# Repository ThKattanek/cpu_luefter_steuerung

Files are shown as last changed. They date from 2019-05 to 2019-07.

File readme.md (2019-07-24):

# CPU-Lüfter Steuerung
Steuerung eines CPU Lüfters per Attiny24a und Anzeige auf 7-Segmentanzeige. Bedienung per Taster.

### [Latest version here](https://github.com/ThKattanek/cpu_luefter_steuerung/releases/latest)

## Bilder
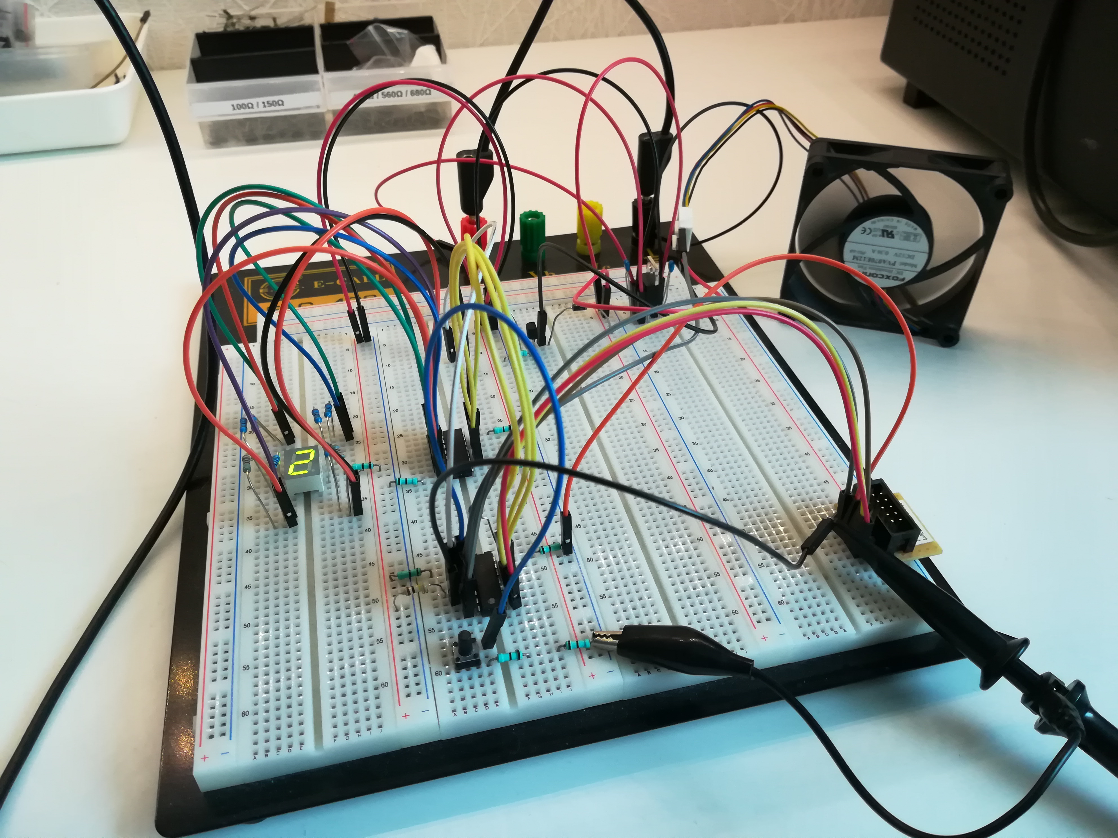
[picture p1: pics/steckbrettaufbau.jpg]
Aufbau

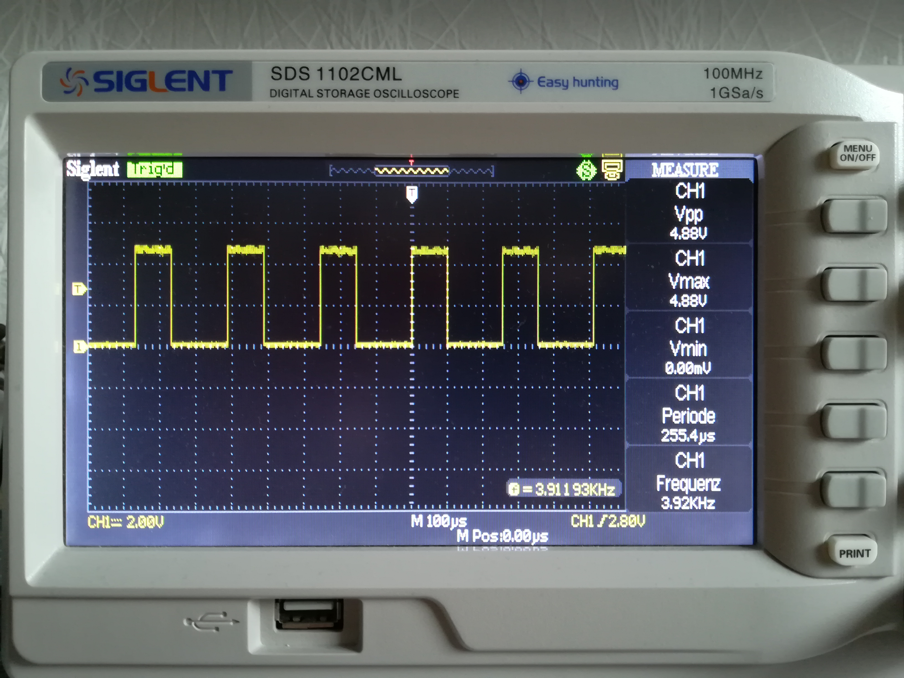
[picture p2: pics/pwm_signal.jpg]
PWM Signal

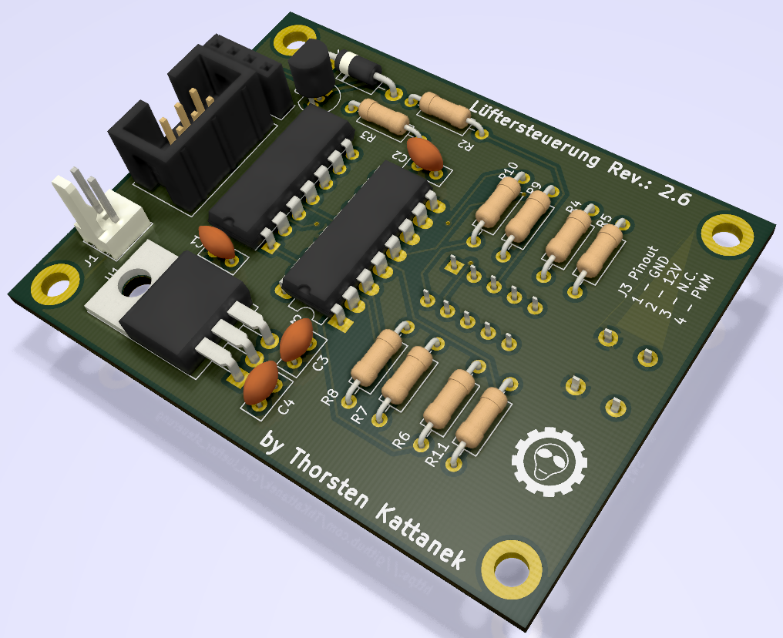
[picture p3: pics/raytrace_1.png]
PCB1

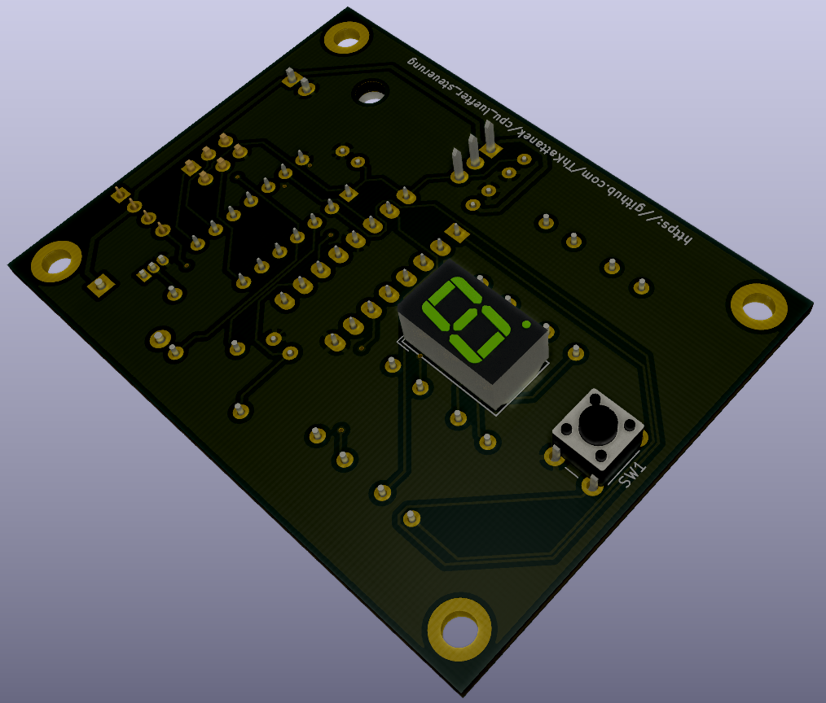
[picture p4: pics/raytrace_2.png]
PCB2


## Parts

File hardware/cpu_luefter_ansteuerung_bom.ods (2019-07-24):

Reference | Value | Footprint
C1 | 100n | Capacitor_THT:C_Disc_D5.0mm_W2.5mm_P2.50mm
C2 | 100n | Capacitor_THT:C_Disc_D5.0mm_W2.5mm_P2.50mm
C3 | 0,33u | Capacitor_THT:C_Disc_D5.0mm_W2.5mm_P2.50mm
C4 | 0,1u | Capacitor_THT:C_Disc_D5.0mm_W2.5mm_P2.50mm
D1 | 1N4001 | Diode_THT:D_DO-41_SOD81_P10.16mm_Horizontal
J1 | Power 12V DC | Connector_Molex:Molex_KK-254_AE-6410-02A_1x02_P2.54mm_Vertical
J2 | ISP | Connector_IDC:IDC-Header_2x03_P2.54mm_Vertical
J3 | CPU Lüfter | Connector_PinSocket_2.54mm:PinSocket_1x04_P2.54mm_Vertical
Q1 | BC337 | Package_TO_SOT_THT:TO-92_Inline
R10 | 560 | Resistor_THT:R_Axial_DIN0207_L6.3mm_D2.5mm_P10.16mm_Horizontal
R11 | 560 | Resistor_THT:R_Axial_DIN0207_L6.3mm_D2.5mm_P10.16mm_Horizontal
R2 | 10k | Resistor_THT:R_Axial_DIN0207_L6.3mm_D2.5mm_P10.16mm_Horizontal
R3 | 220 | Resistor_THT:R_Axial_DIN0207_L6.3mm_D2.5mm_P10.16mm_Horizontal
R4 | 560 | Resistor_THT:R_Axial_DIN0207_L6.3mm_D2.5mm_P10.16mm_Horizontal
R5 | 560 | Resistor_THT:R_Axial_DIN0207_L6.3mm_D2.5mm_P10.16mm_Horizontal
R6 | 560 | Resistor_THT:R_Axial_DIN0207_L6.3mm_D2.5mm_P10.16mm_Horizontal
R7 | 560 | Resistor_THT:R_Axial_DIN0207_L6.3mm_D2.5mm_P10.16mm_Horizontal
R8 | 560 | Resistor_THT:R_Axial_DIN0207_L6.3mm_D2.5mm_P10.16mm_Horizontal
R9 | 560 | Resistor_THT:R_Axial_DIN0207_L6.3mm_D2.5mm_P10.16mm_Horizontal
SW1 | SW_Push | Button_Switch_THT:SW_PUSH_6mm_H5mm
U1 | L7805 | Package_TO_SOT_THT:TO-220-3_Horizontal_TabDown
U2 | ATtiny24A-PU | Package_DIP:DIP-14_W7.62mm
U3 | 74HC595 | Package_DIP:DIP-16_W7.62mm_LongPads
U4 | KCSA02-123 | Display_7Segment:HDSP-7801

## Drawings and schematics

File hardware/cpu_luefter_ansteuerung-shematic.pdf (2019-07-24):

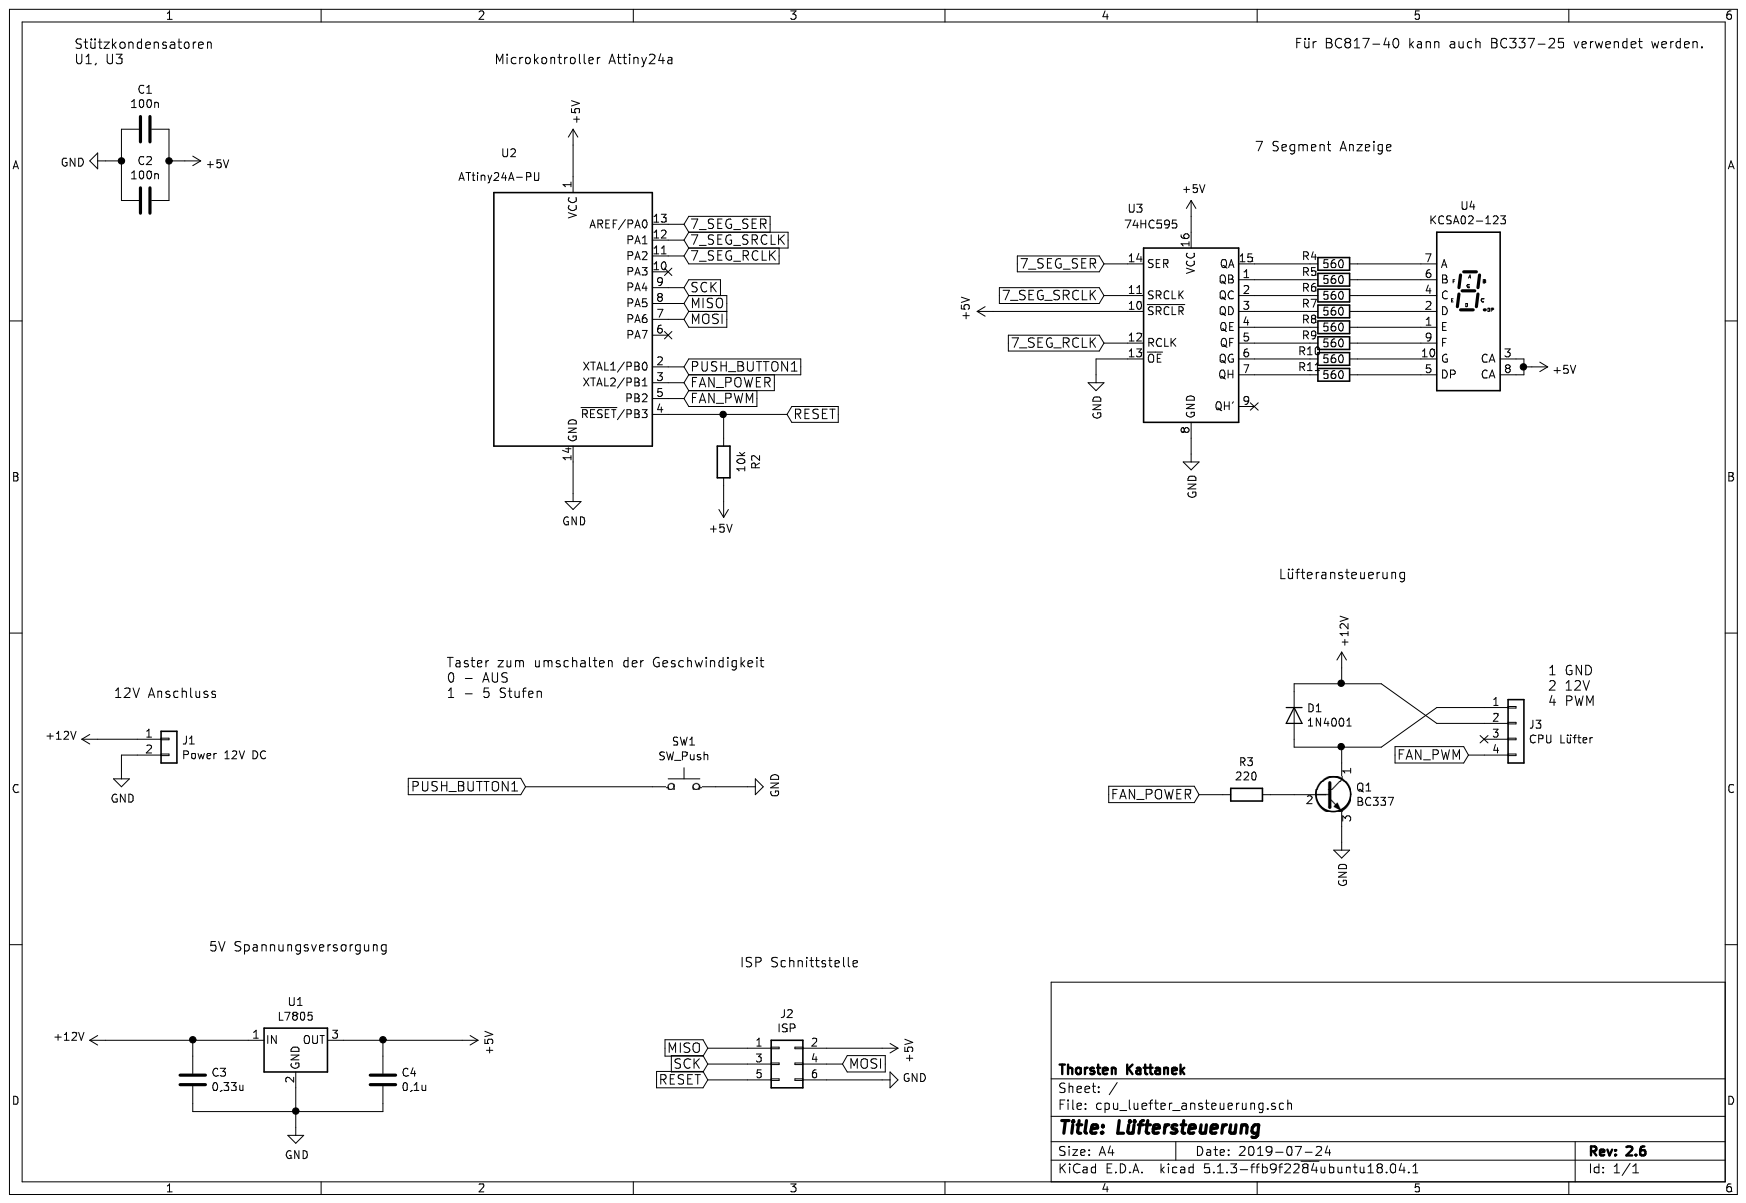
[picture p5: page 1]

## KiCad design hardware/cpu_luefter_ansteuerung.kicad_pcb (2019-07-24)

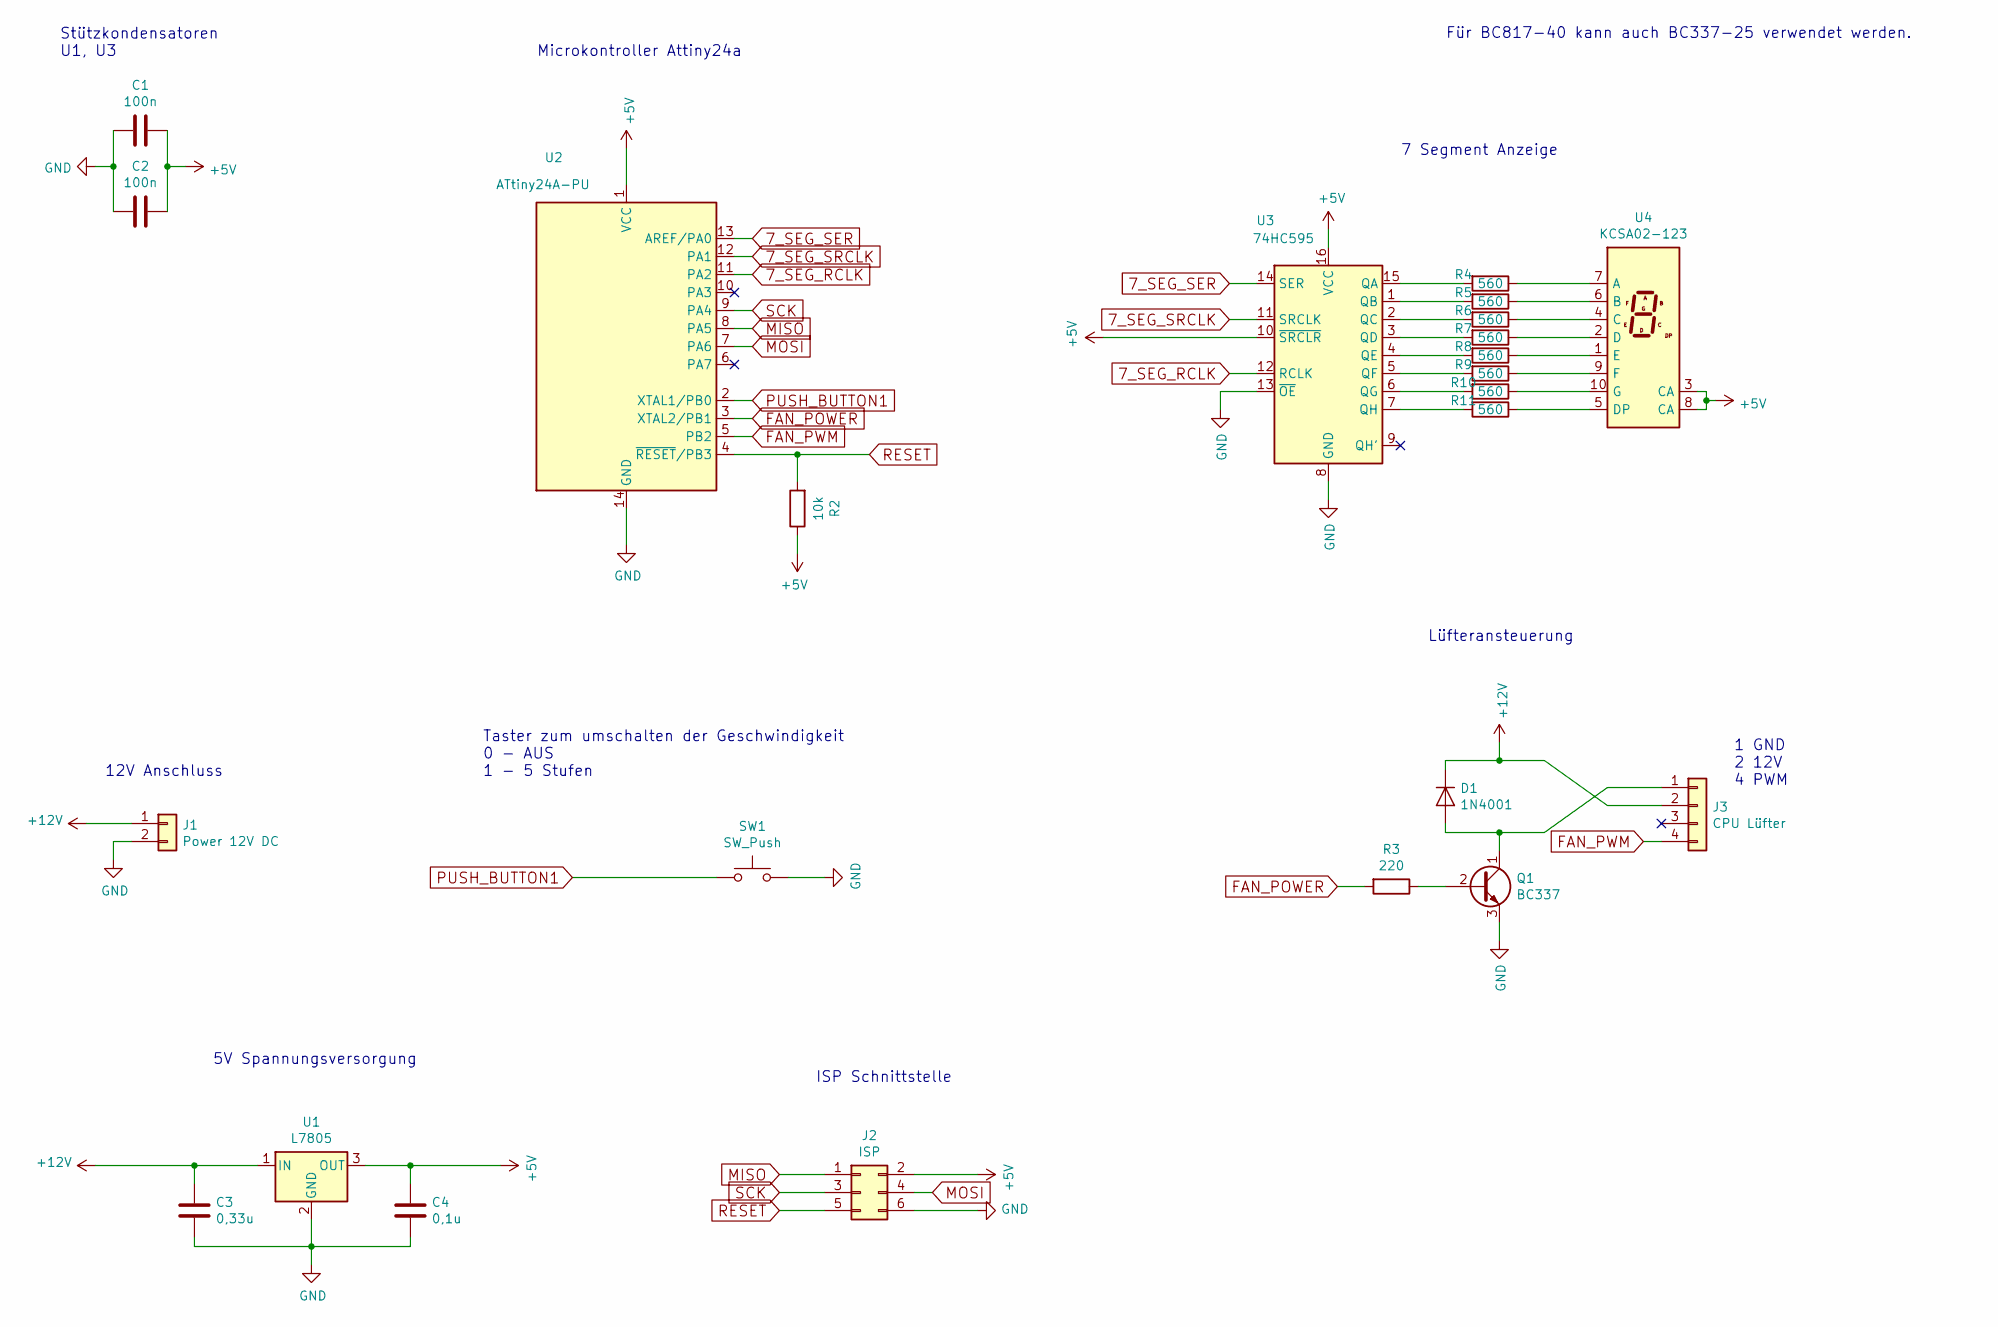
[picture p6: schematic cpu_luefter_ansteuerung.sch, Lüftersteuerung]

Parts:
C1, C2: 100n; C_Disc_D5.0mm_W2.5mm_P2.50mm
C3: 0,33u; C_Disc_D5.0mm_W2.5mm_P2.50mm
C4: 0,1u; C_Disc_D5.0mm_W2.5mm_P2.50mm
D1: 1N4001; D_DO-41_SOD81_P10.16mm_Horizontal
J1: Power 12V DC; Molex_KK-254_AE-6410-02A_1x02_P2.54mm_Vertical
J2: ISP; IDC-Header_2x03_P2.54mm_Vertical
J3: CPU Lüfter; PinSocket_1x04_P2.54mm_Vertical
Q1: BC337; TO-92_Inline
R2: 10k; R_Axial_DIN0207_L6.3mm_D2.5mm_P10.16mm_Horizontal
R3: 220; R_Axial_DIN0207_L6.3mm_D2.5mm_P10.16mm_Horizontal
R4, R5, R6, R7, R8, R9, R10, R11: 560; R_Axial_DIN0207_L6.3mm_D2.5mm_P10.16mm_Horizontal
SW1: SW_Push; SW_PUSH_6mm_H5mm
U1: L7805; TO-220-3_Horizontal_TabDown
U2: ATtiny24A-PU; DIP-14_W7.62mm
U3: 74HC595; DIP-16_W7.62mm_LongPads
U4: KCSA02-123; HDSP-7801

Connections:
7_SEG_RCLK: U2.11 (PA2), U3.12 (RCLK)
7_SEG_SER: U2.13 (AREF/PA0), U3.14 (SER)
7_SEG_SRCLK: U2.12 (PA1), U3.11 (SRCLK)
+5V: C1.1, C2.1, C4.1, J2.2, R2.1, U1.3 (OUT), U2.1 (VCC), U3.10 (~SRCLR), U3.16 (VCC), U4.3 (CA), U4.8 (CA)
+12V: C3.1, D1.1 (K), J1.1, J3.2, U1.1 (IN)
FAN_POWER: R3.2, U2.3 (XTAL2/PB1)
FAN_PWM: J3.4, U2.5 (PB2)
GND: C1.2, C2.2, C3.2, C4.2, J1.2, J2.6, Q1.3 (E), SW1.2, U1.2 (GND), U2.14 (GND), U3.8 (GND), U3.13 (~OE)
MISO: J2.1, U2.8 (PA5)
MOSI: J2.4, U2.7 (PA6)
unnamed: D1.2 (A), J3.1, Q1.1 (C)
unnamed: Q1.2 (B), R3.1
unnamed: R4.1, U4.7 (A)
unnamed: R4.2, U3.15 (QA)
unnamed: R5.1, U4.6 (B)
unnamed: R5.2, U3.1 (QB)
unnamed: R6.1, U4.4 (C)
unnamed: R6.2, U3.2 (QC)
unnamed: R7.1, U4.2 (D)
unnamed: R7.2, U3.3 (QD)
unnamed: R8.1, U4.1 (E)
unnamed: R8.2, U3.4 (QE)
unnamed: R9.1, U4.9 (F)
unnamed: R9.2, U3.5 (QF)
unnamed: R10.1, U4.10 (G)
unnamed: R10.2, U3.6 (QG)
unnamed: R11.1, U4.5 (DP)
unnamed: R11.2, U3.7 (QH)
PUSH_BUTTON1: SW1.1, U2.2 (XTAL1/PB0)
RESET: J2.5, R2.2, U2.4 (~RESET~/PB3)
SCK: J2.3, U2.9 (PA4)

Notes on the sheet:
Für BC817-40 kann auch BC337-25 verwendet werden.
5V Spannungsversorgung
12V Anschluss
Taster zum umschalten der Geschwindigkeit 0 - AUS 1 - 5 Stufen
1 GND 2 12V 4 PWM
Stützkondensatoren U1, U3
ISP Schnittstelle
Microkontroller Attiny24a
7 Segment Anzeige
Lüfteransteuerung

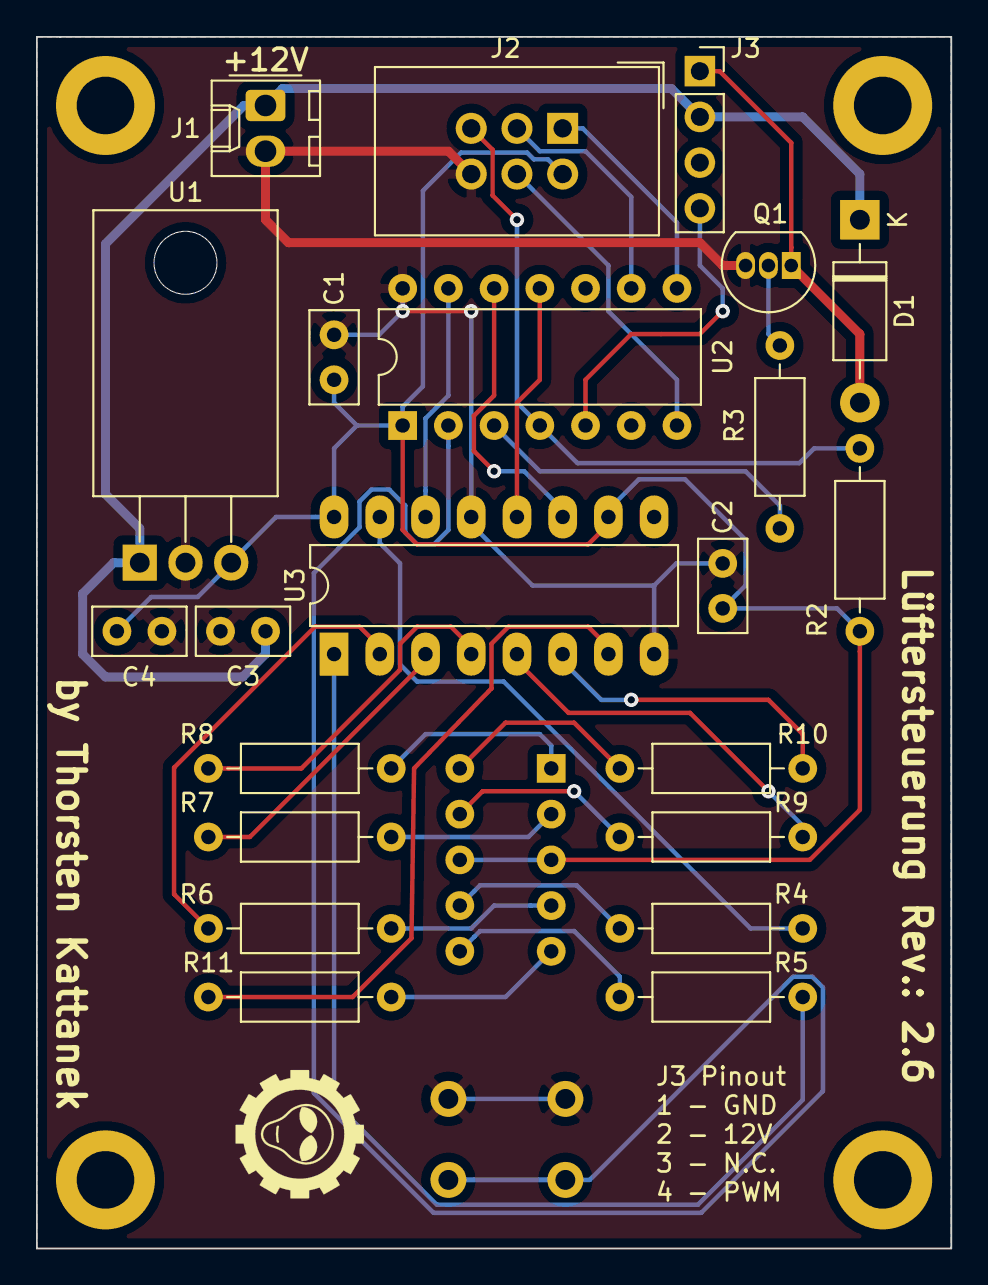
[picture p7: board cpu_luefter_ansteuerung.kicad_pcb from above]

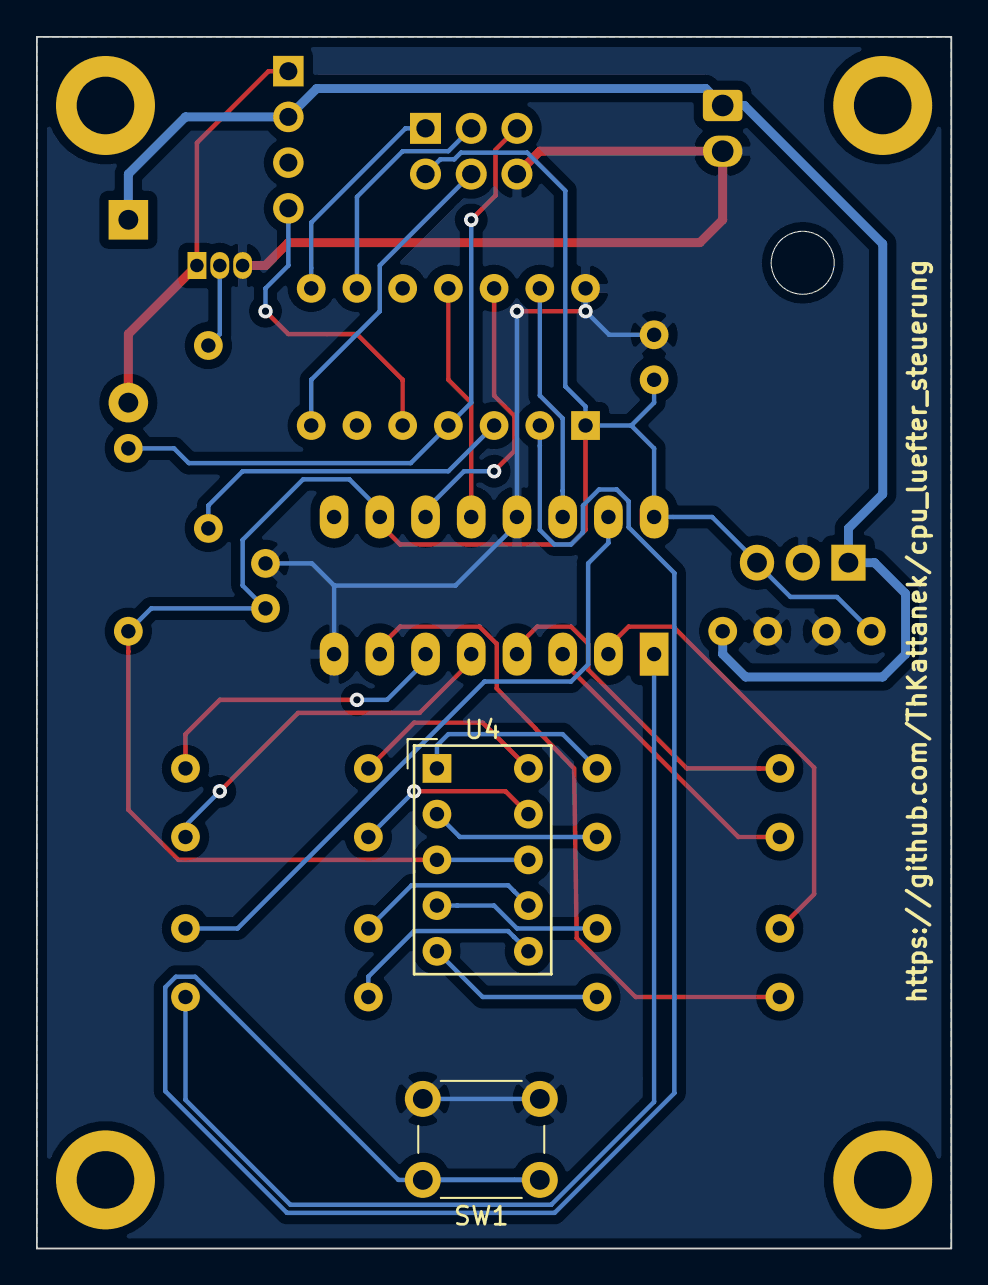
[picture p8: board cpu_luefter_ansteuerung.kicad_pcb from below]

Board: 2 copper layers, 50.8 x 67.3 mm, 24 parts (2 on the bottom side), 31 nets.

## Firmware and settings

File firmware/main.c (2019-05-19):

/* Name: main.c
 * Projekt: cpu_lueftersteuerung
 * Author: Thorsten Kattanek
 * Geändert am: 19.05.2019
 * Copyright: Thorsten Kattanek
 * License: GNU GPL v2 (see License.txt), GNU GPL v3 or proprietary (CommercialLicense.txt)
 *
 */

#define F_CPU   8000000UL
    
#include <avr/io.h>
#include <avr/wdt.h>
#include <avr/interrupt.h>
#include <util/delay.h>
#include <avr/pgmspace.h>   /* benötigt von usbdrv.h */

// PinOut
// PB1 - FAN_POWER
// PB2 - FAN_PWM

// PA0 - 7_SEG_SER
// PA1 - 7_SEG_SRCLK
// PA2 - 7_SEG_RCLK

// PB0 - PUSH_BUTTON1

void InitMotor(void);
void InitPWMChannel(void);
void Init7Segment(void);
void InitInputs(void);

void MotorOn(void);
void MotorOff(void);
void SetMotorSpeed(unsigned char speed);

void Set7Segment(uint8_t value);
void Set7SegmentNumber(uint8_t num);

int main(void)
{
    InitMotor();
    InitPWMChannel();
    Init7Segment();
    InitInputs();

    Set7SegmentNumber(0);

    uint8_t number = 0;

    const uint8_t speed_tbl[6] = {0,50,100,150,200,255};
    uint8_t current_speed = 0; 	// 0 = Aus
    uint8_t key, old_key = 0;
    uint8_t key_wait1 = 0;

    while(1)
    {
        key = (PINB >> PB0) & 1;

        if(key != old_key && key_wait1 == 0)
        {
            if(!key)
            {
                current_speed++;
                if(current_speed == 6)
                    current_speed = 0;
                Set7SegmentNumber(current_speed);

                if(current_speed == 0)
                    MotorOff();
                else
                    MotorOn();

                SetMotorSpeed(speed_tbl[current_speed]);
            }
            key_wait1 = 0xff;
        }
        else if(key_wait1 > 0) {
            key_wait1--;
        }

        old_key = key;
    }
}

/* ------------------------------------------------------------------------- */

void InitMotor(void)
{
    // Motor On/Off Signal muss definiert 5V oder GND haben.
    DDRB |= 1 << PB1;
    PORTB &= ~(1 << PB1);
}

void InitPWMChannel(void)
{
    DDRB |= 1 << PB2;                                   // OC0A auf Ausgang setzen
    TCCR0A |= 1 << COM0A1 | 1 << WGM00 | 1 << WGM01;     // OC0A non-invertmode - FAST PWM Mode
    TCCR0B |= 1 << CS01;                                 // Prescaler auf 8 --> 8MHz / 8 / 256 = 3,9 KHz
    OCR0A = 0;
}

void Init7Segment(void)
{
    DDRA |= 1 << PA0 | 1 << PA1 | 1 << PA2;

    PORTA |= 1 << PA0;       // SER auf HI -> LED AUS

    PORTA &= ~(1 << PA1 | 1 << PA2);    // SRCLK & RCLK auf Low setzen

    for(int i=0; i<8; i++)      // SRCLK 8x
    {
        PORTA |= 1 << PA1;
        PORTA &= ~(1 << PA1);
    }

    PORTA |= 1 << PA2;      // RCLK 1x
    PORTA &= ~(1 << PA2);
}

void InitInputs(void)
{
    DDRB &= ~(1 << PB0);
    PINB |= 1 << PB0;      // Set intern pullups
}

void Set7Segment(uint8_t value)
{
    for(int i=0; i<8; i++)
    {
        PORTA &= 0xfe;                      // SER loeschen
        PORTA |= (value >> (7-i)) & 0x01;   // SER mit Bit füllen
        PORTA ^= 0x01;                      // SER invertieren

        PORTA |= 1 << PA1;                  // SRCLK
        PORTA &= ~(1 << PA1);
    }

    PORTA |= 1 << PA2;                      // RCLK 1x
    PORTA &= ~(1 << PA2);
}

void Set7SegmentNumber(uint8_t num)
{
    const uint8_t num_conv_tbl[10] = {0xed, 0x21, 0xf4, 0xf1, 0x39, 0xd9, 0xdd, 0x61, 0xfd, 0xf9};

    if(num < 10)
    Set7Segment(num_conv_tbl[num]);
}

///
/// \brief MotorOn
///
void MotorOn(void)
{
    PORTB |= 1 << PB1;
}

///
/// \brief MotorOff
///
void MotorOff(void)
{
    PORTB &= ~(1 << PB1);
}

///
/// \brief SetMotorSpeed
/// \param speed = 0-255 (0=slow 255=fast)
///
void SetMotorSpeed(unsigned char speed)
{
    OCR0A = speed;
}

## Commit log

2019-05-06 Portierung zu KiCad 5.1.2
    [cpu_luefter_ansteuerung.csv, cpu_luefter_ansteuerung.kicad_pcb, cpu_luefter_ansteuerung.sch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]
2019-05-09 Hardware auf ATiny24A umgestellt und statt 4543 jetzt ein Leistungs Shiftregister für 7Segment ansteuerung.
    [cpu_luefter_ansteuerung.sch]
2019-05-15 Schaltplan etwas optimiert -> Rev: 2.1
    [cpu_luefter_ansteuerung.sch]
2019-05-15 Schaltplan optimiert -> Rev: 2.2 TPIC6B595 durch 74HC595 ersetzt. Alle Bauteile Footprints zugewiesen.
    [cpu_luefter_ansteuerung.sch]
2019-05-15 Angefangen die Firmware an neuen Schaltplan anzupassen.
2019-05-17 Vorwiderstaende fuer 7Segment Anzeige von 150 Ohm auf 560 Ohm geaendert. 74HC595 darf nur gesammt 70mA treiben.
    [cpu_luefter_ansteuerung.sch]
2019-05-17 Fix im Schaltplan.
    [cpu_luefter_ansteuerung.sch]
2019-05-19 Firmware fertig gestellt. Push Button auf Internen Pullup gestellt und Soft Entprellung eingesetzt. Spart 1 Kondensator und 1 Widerstand.
2019-05-19 Schaltplan an neuer Firmware angepasst.
    [cpu_luefter_ansteuerung.sch]
2019-05-21 pcb angefangen, Bauteile schon mal angeordnet.
    [cpu_luefter_ansteuerung.kicad_pcb]
2019-05-23 PCB Hand geroutet.
    [cpu_luefter_ansteuerung.kicad_pcb]
2019-05-23 Display + Taster auf Bottom Layer gelegt. STEP Datei erzeugt.
    [cpu_luefter_ansteuerung.kicad_pcb]
2019-05-23 PCB habe ich mit meinem Logo versehen und Beschriftet
    [cpu_luefter_ansteuerung.kicad_pcb]
2019-06-13 PCB - Bestückungsdruck bereinigt
    [cpu_luefter_ansteuerung.kicad_pcb]
2019-06-13 Gerberfiles erzeugt
    [cpu_luefter_ansteuerung-B_Cu.gbl, cpu_luefter_ansteuerung-B_Mask.gbs, cpu_luefter_ansteuerung-B_Paste.gbp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]
2019-06-19 cpu_luefter_ansteuerung_bom.ods ninzugefuegt.
    [cpu_luefter_ansteuerung.ods, cpu_luefter_ansteuerung_bom.ods]
2019-06-20 Shematic und PCB für 7805 korrigiert. Neue Gerber Dateien erzeugt
    [cpu_luefter_ansteuerung-B_Cu.gbl, cpu_luefter_ansteuerung-B_Mask.gbs, cpu_luefter_ansteuerung-B_Paste.gbp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]
2019-07-24 J3 Footprint geändert
    [cpu_luefter_ansteuerung.kicad_pcb, cpu_luefter_ansteuerung.sch]
2019-07-24 Schematic auf Version 2.6 angepasst
    [cpu_luefter_ansteuerung.sch]
2019-07-24 Logo wieder eingefügt
    [cpu_luefter_ansteuerung.kicad_pcb]
2019-07-24 Gerber Dateien aktuallisiert
2019-07-24 Stückliste angepasst
    [cpu_luefter_ansteuerung_bom.ods]
